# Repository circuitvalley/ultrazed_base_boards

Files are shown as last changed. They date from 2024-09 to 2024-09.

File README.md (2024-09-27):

# Ultrabase : Open source Ultrazed PCIe Carrier Card for Xilinx AMD Zynq Ultrascale+ FPGA SOC SOM
This repository contains Design files for Various Base board Designed for Avnet Zynq Ultrascale+ FPGA SOC

Board Features
--------------
- PS PCIe x1 Gen2 
- PS USB 3.0
- PS SATA 6Gbps
- PS Mini Display Port
- Gigabit Ethernet 
- microSD card 
- PL expansion Port
- PS and PL LEDs
- PL DIP Switch 
- Reset and PL Switch
- PLL Clock Gen
- PMIC Regulator

Shield: [][cc-by]

This work is licensed under a [Creative Commons Attribution 4.0 International
License][cc-by].

[][cc-by]

[cc-by]: http://creativecommons.org/licenses/by/4.0/
[cc-by-image]: https://i.creativecommons.org/l/by/4.0/88x31.png
[cc-by-shield]: https://img.shields.io/badge/License-CC%20BY%204.0-lightgrey.svg

<a href="https://www.youtube.com/watch?v=APrIkn0p9bU">
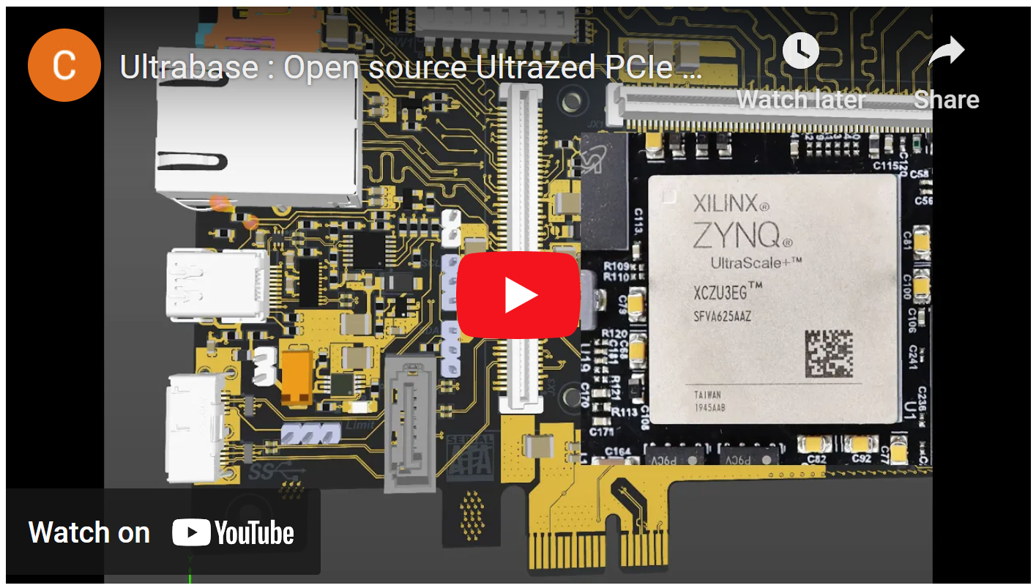
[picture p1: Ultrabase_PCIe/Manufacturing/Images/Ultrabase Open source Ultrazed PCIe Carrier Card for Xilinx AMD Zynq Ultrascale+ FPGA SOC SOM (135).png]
Ultrascale+

</a>


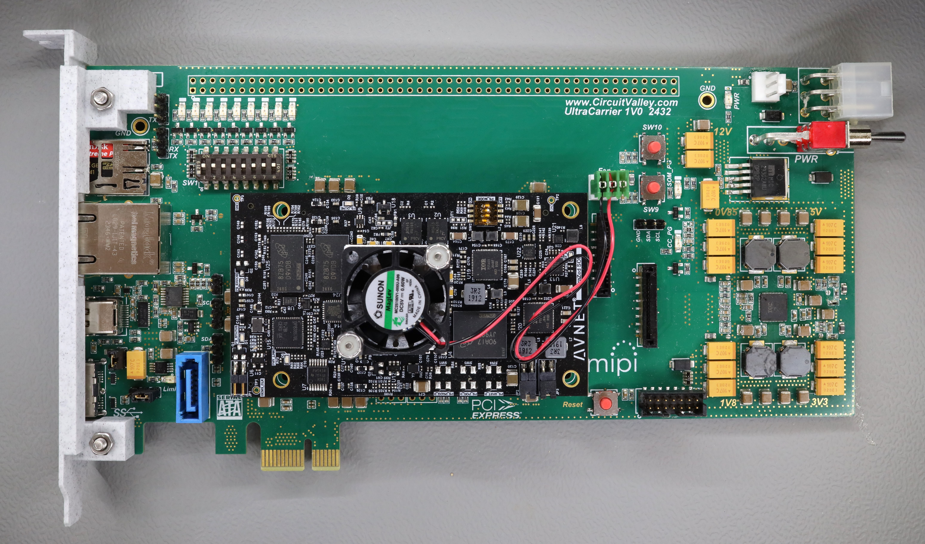
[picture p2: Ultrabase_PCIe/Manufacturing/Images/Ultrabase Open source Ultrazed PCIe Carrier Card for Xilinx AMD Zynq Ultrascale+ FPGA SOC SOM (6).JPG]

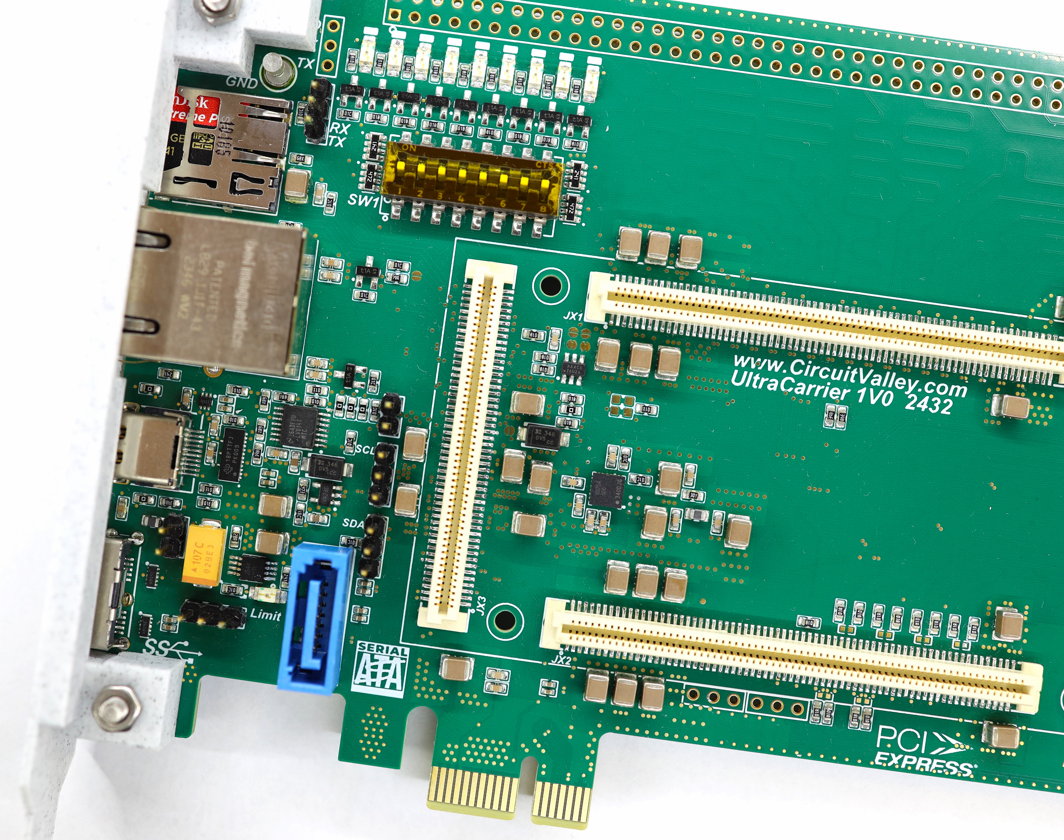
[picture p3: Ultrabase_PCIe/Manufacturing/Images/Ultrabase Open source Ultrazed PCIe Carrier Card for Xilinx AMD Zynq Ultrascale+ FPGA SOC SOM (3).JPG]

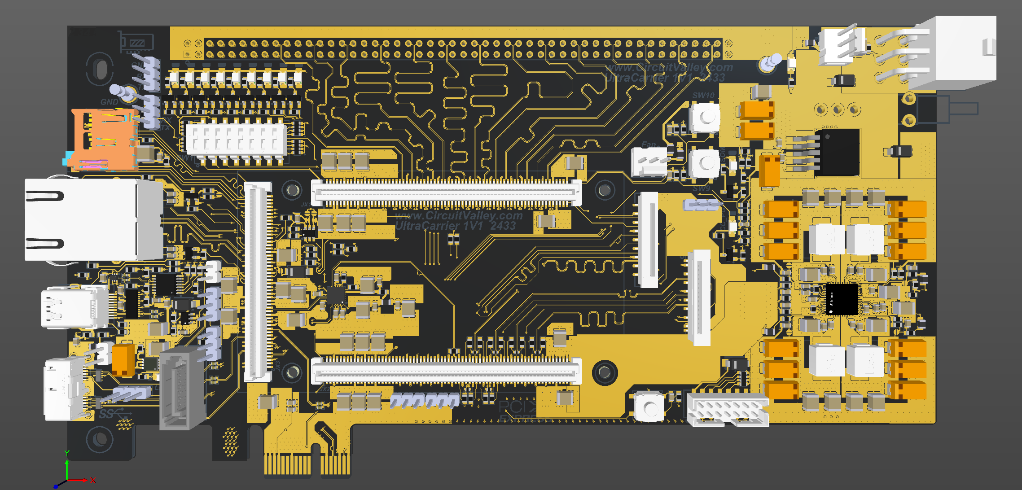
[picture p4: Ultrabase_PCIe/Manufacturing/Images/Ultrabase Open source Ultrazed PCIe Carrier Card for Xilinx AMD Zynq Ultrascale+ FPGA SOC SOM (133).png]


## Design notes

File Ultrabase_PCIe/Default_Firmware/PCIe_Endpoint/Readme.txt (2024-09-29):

BOOT.bin present in this folder will be detected as PCIe Endpoint with LED counter

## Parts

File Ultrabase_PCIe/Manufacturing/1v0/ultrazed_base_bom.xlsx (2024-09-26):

Comment | Description | Designator | Footprint | LibRef | Quantity | Value | JLCPCB Part #
10µ | Capacitor SMD Cer 10uF 20% 16V X5R 1210 | C1, C2, C3, C4, C5, C6, C7, C8, C9, C10, C11, C12, C13, C14, C15, C16, C17, C18, C19, C20, C21, C27, C35, C48, C60, C62, C70, C75, C76, C77, C78, C83, C84, C95, C97, C99, C109, C110, C111, C112, C116, C118, C121, C124, C125 | CAPC3225N | CAPC_10u_1210_50V | 45 | 10µ | C337455
100n | Capacitor SMD Cer 120pF 10% 50V C0G 0603, Capacitor SMD Cer 1nF 10% 100V X7R 0603 | C22, C24, C29, C31, C34, C40, C41, C42, C43, C49, C53, C54, C64, C67, C68, C69, C89, C90, C91, C92, C93, C96, C98, C100, C123, C126, C127, C128, C129 | CAPC1608N | CAPC_120p_0603_C0G_50V, CAPC_1n_0603_100V | 29 | 100n | C14663
100n | Capacitor SMD Cer 100nF 10% 16V X5R 0402 | C25, C26, C36, C37, C38, C39, C44, C45, C46, C47, C65, C66 | CAPC1005N | CAPC_100n_0402_16V_10% | 12 | 100n | C307331
47uf 20V D | Capacitor SMD Tant 330uF 20% 6V3 2917 | C33, C61, C71, C72, C73, C74, C79, C80, C81, C82, C101, C102, C103, C104, C119, C120 | CAPMP7343X310N | CAPT_330u_2917_6V3 | 16 | 22uf 20V D | C11379
4u7 | Capacitor SMD Cer 120pF 10% 50V C0G 0603 | C50, C51, C52 | CAPC1608N | CAPC_120p_0603_C0G_50V | 3 | 4u7 | C268021
10n | Capacitor SMD Cer 120pF 10% 50V C0G 0603 | C55, C56, C57, C58, C59, C85, C86, C87, C88 | CAPC1608N | CAPC_120p_0603_C0G_50V | 9 | 10n | C100042
1u | Capacitor SMD Cer 120pF 10% 50V C0G 0603 | C63, C94, C105, C106, C107, C108, C113, C114, C115 | CAPC1608N | CAPC_120p_0603_C0G_50V | 9 | 1u | C5673
TPD8S009DSMR | Display Port ESD | D1 | WSON-15 | TPD8S009DSMR | 1 |  | C471873
TPD4E001DRLR | ESD Protection | D2 | SOT5x3 | TPD4E001DRLR | 1 |  | C527516
SDT5A50SA-13 | Diode | D3, D4, D5, D6, D20 | DO-214AC | Diode | 5
LED | LED | D7, D8, D9, D10, D11, D12, D13, D14, D15, D16, D17, D18, D19 | 1206_LED | LED | 13 |  | C125107
PCIe_x1 | PCIe X1 Card edge | J1 | PCIe_x1 | PCIe_x1 | 1
GTFP08441BEU | MicroSD card | J2 | GTFP08441BEU | GTFP08441BEU | 1
1586041-6 | PCIE Molex Power | J3 | 1586043-6 | 1586041-6 | 1
SAT3M3232042TR | Sata Connector Vertical | J5 | SAT3M3232042TR | SAT3M3232042TR | 1
L829-1J1T-43 | MagJack 1000BASE-T | 1X1 | 3w-OG/Y | Tab Up | Low Profile | RoHS | J6 | L829-1J1T-43 | L829-1J1T-43 | 1
GSB343T33HR | USB3.2 Micro B | J7 | GSB343T33HR | GSB343T33HR | 1
G46M2023201AWEU | Mini Display Port | J8 | G46M2023201AWEU | G46M2023201AWEU | 1
22292031 | 22292031 | J13, J23 | 22-23-2031 | 22292031 | 2
part |  | J15 | PART | part | 1
JTAG | JTAG | J19 | 878321420 | Xilinx_JTAG | 1
SFW15S | 15 pin 1mm FPC, RPI Camera | J20, J21 | SFW15S-2STMAE1LF | SFW15S | 2
Female/Receptcale | 140 Pin Ultrascale SOM Connector with ultrazed specific SOM net delay | JX1, JX2 | 5177985-6 | 5177985-6_Ultrazed_JX1, 5177985-6_Ultrazed_JX2 | 2
Female/Receptcale | 100 Pin Ultrascale SOM Connector with ultrazed specific SOM net delay | JX3 | 5177985-4 | 5177985-4_Ultrazed | 1
3.3uh |  | L1, L2, L3 | 1217AS-H-3R3N=P3 | inductor_smd | 3
1.5uh |  | L4 | 1217AS-H-3R3N=P3 | inductor_smd | 1
Ferrite | Ferrite Bead | L5, L6, L7, L8, L9, L10, L11, L12, L13 | FBC2012N | Ferrite Bead | 9 |  | C85840
Ultrazed Mechanical |  | M1 | ULTRAZED_SOM_Mechanical | UltrazedSOMMechanical | 1
Header | 2 Pin Header | P1, P4 | Header2x | Header_2Pin | 2
Header | 3 Pin Header | P2, P3, P5, P6, P7, P8, P9, P10 | Header3x | Header_3Pin | 8
NPN_MMBT3904 | Transistor SMD NPN 40V 0.2A 350mW SOT-23 | Q1, Q2, Q3, Q4, Q5, Q6, Q7, Q8, Q9, Q10, Q11, Q12, Q13 | SOT23-3 | NPN_MMBT3904 | 13 |  | C8667
RES_NL_0603 | Resistor, SMD chip | R1, R42, R43, R47, R49, R52, R53 | RESC1608N | RES_NL_0603 | 7 | 649R | C705870
RES_NL_0603 | Resistor, SMD chip | R2, R57, R94, R95, R97, R98, R100, R101, R103, R104, R106, R107, R109, R110, R112 | RESC1608N | RES_NL_0603 | 15 | 100R | C122970
RES_NL_0603 | Resistor, SMD chip | R3 | RESC1608N | RES_NL_0603 | 1 | 20K | C723637
RES_NL_0603 | Resistor, SMD chip | R4 | RESC1608N | RES_NL_0603 | 1 | 12K | C326735
RES_NL_0603 | Resistor, SMD chip | R5, R6, R8, R10, R11, R17, R23, R27, R29, R55, R58, R59, R78, R80, R82, R83, R84, R114, R116 | RESC1608N | RES_NL_0603 | 19 | 10K | C95204
RES_NL_0603 | Resistor, SMD chip | R7, R35, R37 | RESC1608N | RES_NL_0603 | 3 | 49R9 | C861434
RES_NL_0603 | Resistor, SMD chip | R9, R16, R21, R26, R33, R34, R38, R41 | RESC1608N | RES_NL_0603 | 8 | 0R | C95177
RES_NL_0603 | Resistor, SMD chip | R12, R44, R45, R46, R50, R54 | RESC1608N | RES_NL_0603 | 6 | 10R | C700510
RES_NL_0603 | Resistor, SMD chip | R13, R14, R28 | RESC1608N | RES_NL_0603 | 3 | 1M | C326730
RES_NL_0603 | Resistor, SMD chip | R15, R36, R39 | RESC1608N | RES_NL_0603 | 3 | 100K | C122538
RES_NL_0603 | Resistor, SMD chip | R18, R108, R111, R113, R115 | RESC1608N | RES_NL_0603 | 5 | 240R | C705750
RES_NL_0603 | Resistor, SMD chip | R19 | RESC1608N | RES_NL_0603 | 1 | 191R | C144692
RES_NL_0603 | Resistor, SMD chip | R20, R31, R81, R102, R105 | RESC1608N | RES_NL_0603 | 5 | 2K49 | C861299
RES_NL_0603 | Resistor, SMD chip | R22, R76 | RESC1608N | RES_NL_0603 | 2 | 2R | C723696
RES_NL_0603 | Resistor, SMD chip | R24, R30 | RESC1608N | RES_NL_0603 | 2 | 1.78K | C861207
RES_NL_0603 | Resistor, SMD chip | R25 | RESC1608N | RES_NL_0603 | 1 | 10K NC
RES_NL_0603 | Resistor, SMD chip | R32 | RESC1608N | RES_NL_0603 | 1 | 1K5 | C705741
RES_NL_0603 | Resistor, SMD chip | R40, R56, R60, R61, R62, R63, R64, R65, R66, R67, R68, R69, R70, R71, R72, R73, R74, R75, R77, R79, R87, R88, R89, R117 | RESC1608N | RES_NL_0603 | 24 | 1K | C110776
RES_NL_0603 | Resistor, SMD chip | R48, R51 | RESC1608N | RES_NL_0603 | 2 | 10R NC
RES_NL_0603 | Resistor, SMD chip | R85 | RESC1608N | RES_NL_0603 | 1 | 47K | C326725
RES_NL_0603 | Resistor, SMD chip | R86 | RESC1608N | RES_NL_0603 | 1 | 15K | C326733
Thick Film | Resistor SMD chip 3.3k Ohm 0.063W 5% 0402 | R90, R91, R92, R93, R96, R99 | RESC1005N | RES_3K3_0402_5% | 6 | NC100R
Thick Film | Resistor array 4-pack 5% 0402 SMD | RA1, RA2 | YC164 | RES_ARRAY_0402_5% | 2 | 240R | C327051
Thick Film | Resistor array 4-pack 5% 0402 SMD | RA3, RA4, RA5 | YC164 | RES_ARRAY_0402_5% | 3 | 4.7K | C327044
DIP-Switch-8 219-8MST | DIP Switch 8 Position | SW1 | 219-8MST | DIP-Switch-8 | 1 |  | C2842674
Switch | Switch SPDT | SW2 | 1MS1T1B4M7QES | Switch_SPDT | 1
222KJVAAR |  | SW3, SW4, SW5 | 222KJVAAR | PushButton | 3
TestHook |  | T25, T26 | 1502-x | TestHook | 2
MIC29302WU |  | U1 | TO-263-5 | MIC29302WU | 1
TPD4E05U06DQAR | ESD Protection | U2, U4 | uDFN-10 | TPD4E05U06DQAR | 2 |  | C138714
MIC2544-1YMM | High Side Switch, Current limit programmable | U3 | MSOP8 | MIC2544 | 1
IRPS5401M | PMIC Flexible Power Management Unit | U5 | INF-PG-QFN-56-7X7 | IRPS5401M | 1
FIN1019MTCX | Differential Buffer | U6 | TSSOP14 PW G14 | FIN1019MTCX | 1
5P49V6975A000LTGI | Programmable Clock Generators | U7 | LGA24 | 5P49V6975 | 1
AP7365-WG-7 | LDO Reg ADJ 600mA | U8 | SOT23-5 | AP7365-WG-7 | 1
24AA025E | MAC EEPROM | U9 | SOT23-6 | 24AA025E | 1

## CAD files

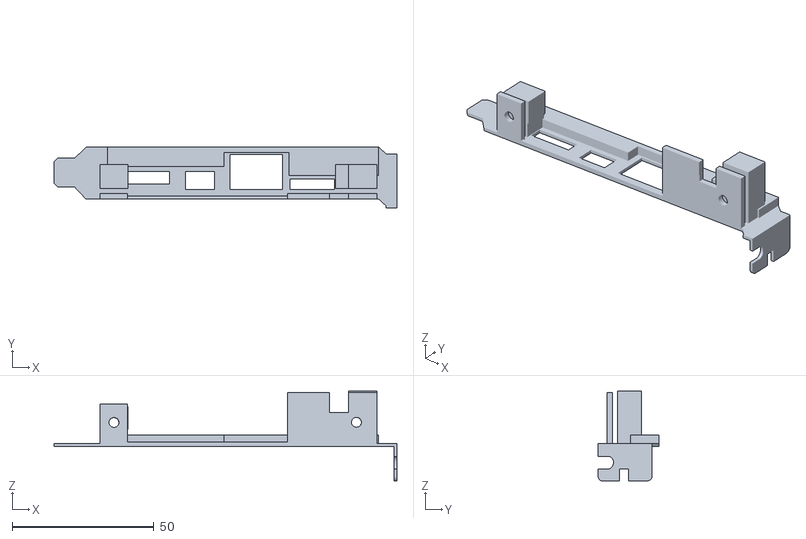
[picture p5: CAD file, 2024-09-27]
Ultrabase_PCIe/Manufacturing/PCIe_Bracket.stl
120.8 x 21.4 x 31.6

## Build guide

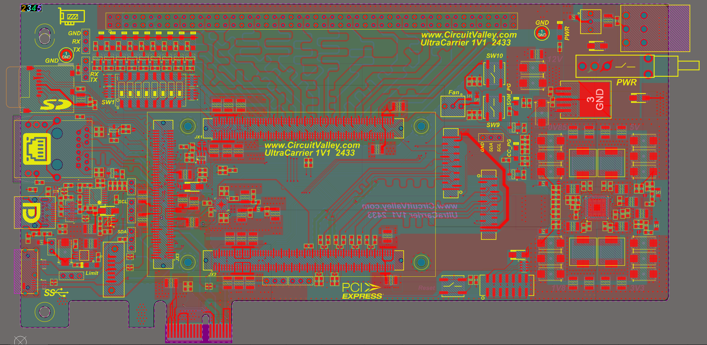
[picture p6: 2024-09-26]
Ultrabase_PCIe/Manufacturing/Images/Ultrabase Open source Ultrazed PCIe Carrier Card for Xilinx AMD Zynq Ultrascale+ FPGA SOC SOM (134).png

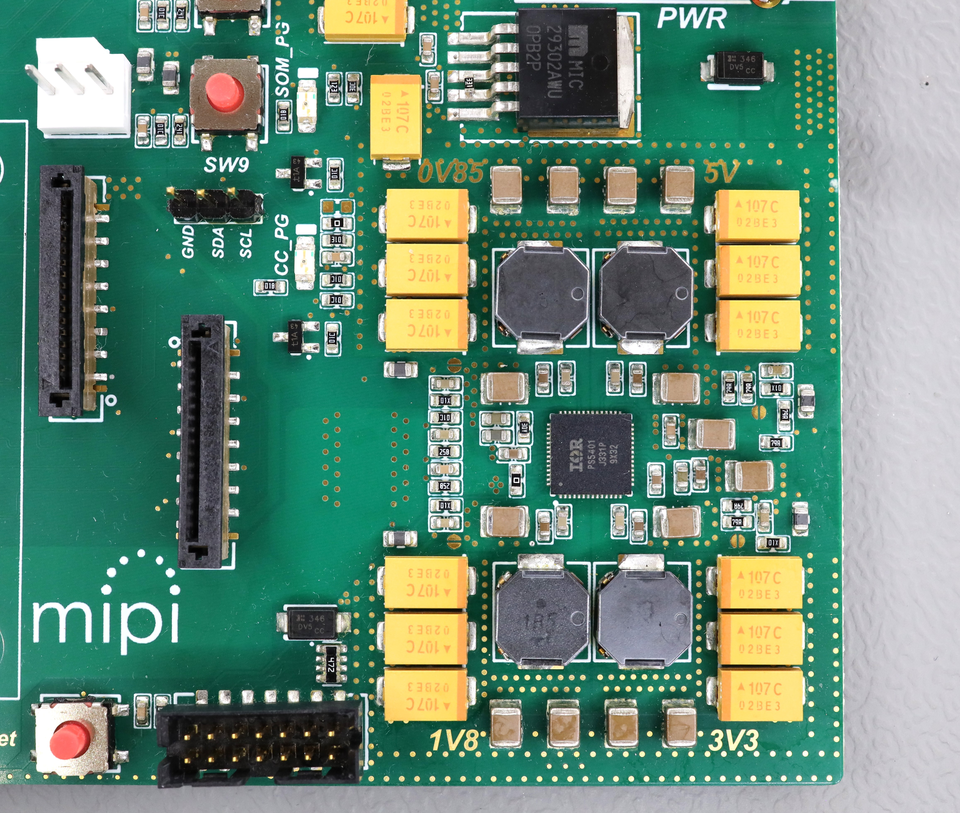
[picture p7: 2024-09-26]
Ultrabase_PCIe/Manufacturing/Images/Ultrabase Open source Ultrazed PCIe Carrier Card for Xilinx AMD Zynq Ultrascale+ FPGA SOC SOM (11).JPG

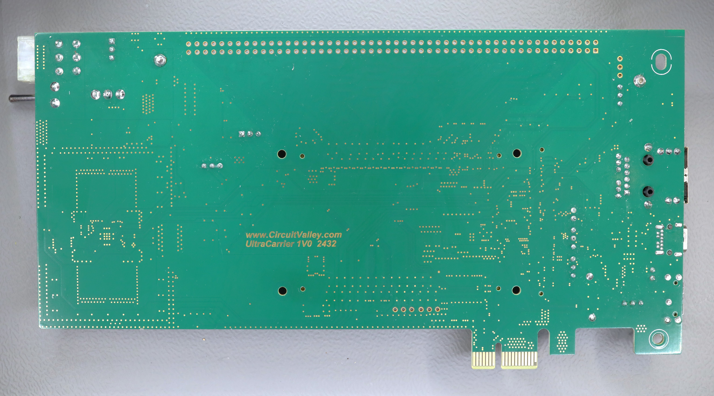
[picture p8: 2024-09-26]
Ultrabase_PCIe/Manufacturing/Images/Ultrabase Open source Ultrazed PCIe Carrier Card for Xilinx AMD Zynq Ultrascale+ FPGA SOC SOM (1444).JPG

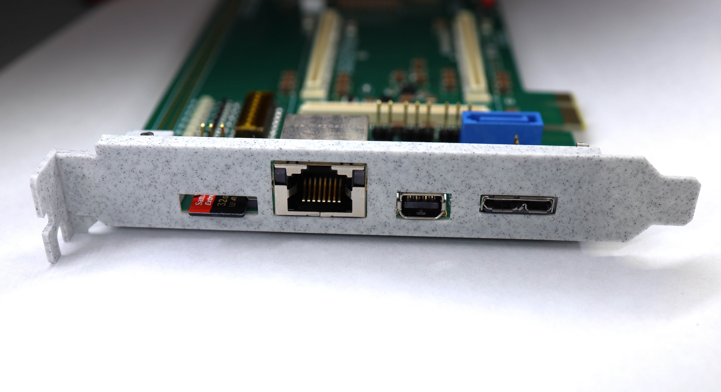
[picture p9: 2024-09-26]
Ultrabase_PCIe/Manufacturing/Images/Ultrabase Open source Ultrazed PCIe Carrier Card for Xilinx AMD Zynq Ultrascale+ FPGA SOC SOM (2).JPG

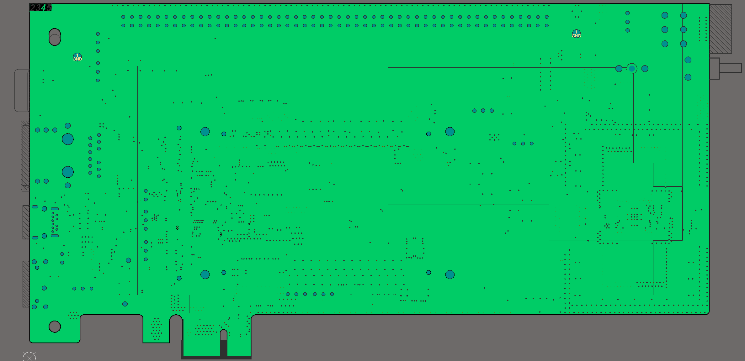
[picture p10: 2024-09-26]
Ultrabase_PCIe/Manufacturing/Images/Ultrabase Open source Ultrazed PCIe Carrier Card for Xilinx AMD Zynq Ultrascale+ FPGA SOC SOM (5).png

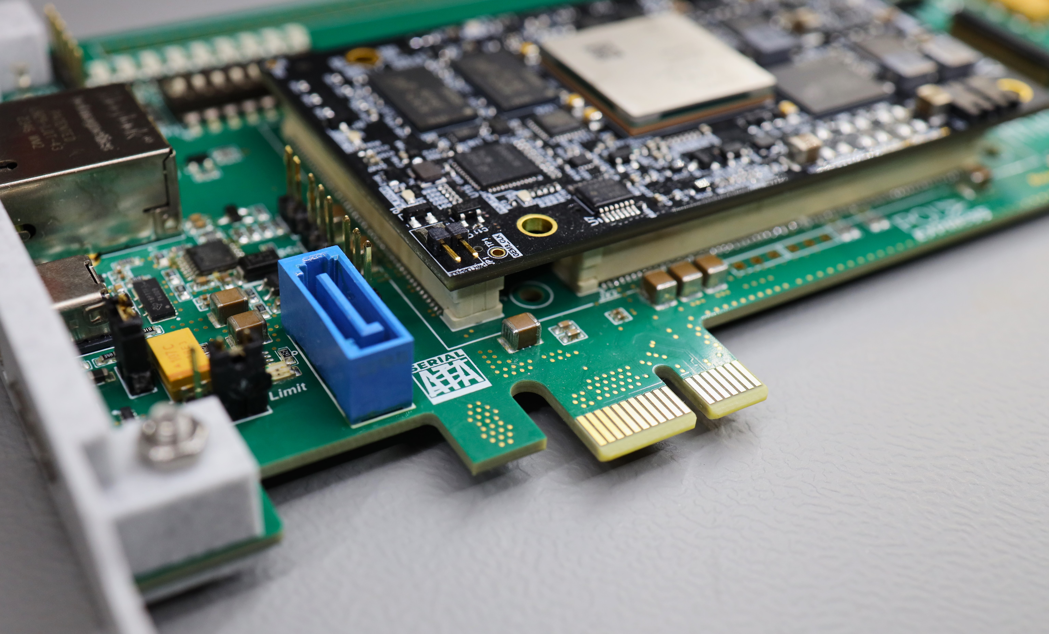
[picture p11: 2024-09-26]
Ultrabase_PCIe/Manufacturing/Images/Ultrabase Open source Ultrazed PCIe Carrier Card for Xilinx AMD Zynq Ultrascale+ FPGA SOC SOM (8).JPG

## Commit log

2024-09-26 Added Ultrabase_PCIe_x1 First release
    [Clock.SchDoc, DisplayPort.SchDoc, Ethernet.SchDoc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]
2024-09-26 Added Board Image to README.md
2024-09-27 Added PCIe_Bracket.stl
    [PCIe_Bracket.stl]

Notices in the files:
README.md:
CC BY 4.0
